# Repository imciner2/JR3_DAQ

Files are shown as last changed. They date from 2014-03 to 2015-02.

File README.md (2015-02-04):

JR3_DAQ
=======

Analog Data Acquisition unit for a JR3 Force/Moment sensor.

## Requirements:
* All connections must be idiot-proof
* Sealed box, only JR3 connector, computer connector, power connector
*	Raw voltage must be recorded

## Sensor:
It must interface with a JR3	67M25A3-I40-AH 200N. That sensor has the following features:
*	Requires a +-12V supply
*	Provides a +-10V output

## Digital Acquisition Hardware
It uses a NI USB-6221 DAQ in the OEM form-factor. That sensor has the following features:
*	16 analog inputs
*	250kS/s
*	Labview interface
*	http://sine.ni.com/nips/cds/view/p/lang/en/nid/209809
*	34-pin ribbon cable connector

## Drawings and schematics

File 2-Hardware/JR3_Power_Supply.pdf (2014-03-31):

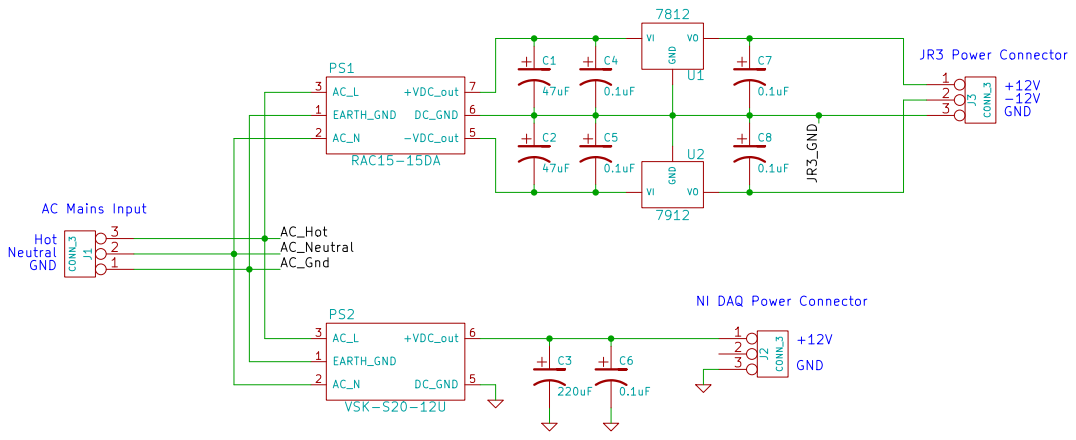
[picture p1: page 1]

AC Mains Input Hot Neutral GND

Drawn By: Ian McInerney
Iowa State University
File: JR3_Power_Supply.sch
Sheet: /
Title: JR3 DAQ Power Supply

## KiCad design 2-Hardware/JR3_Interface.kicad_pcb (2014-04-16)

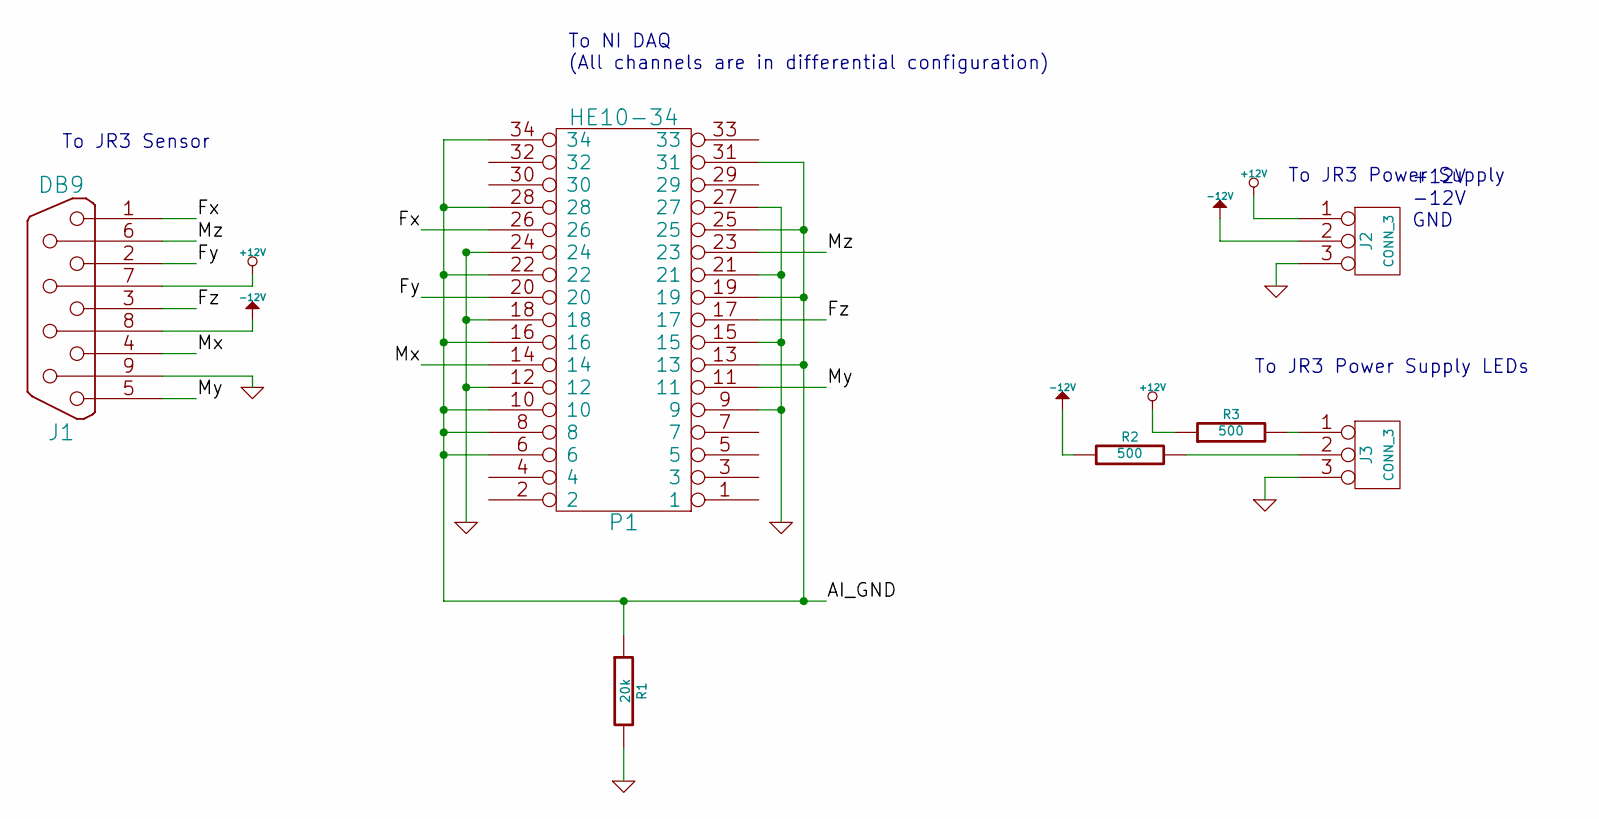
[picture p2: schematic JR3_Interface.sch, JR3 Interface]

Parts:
J1: DB9
J2, J3: CONN_3
P1: HE10-34
R1: 20k
R2, R3: 500

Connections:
+12V: J1.7, J2.1, R3.1
-12V: J1.8, J2.2 (PM), R2.1
/AI_GND: P1.6, P1.8, P1.10, P1.13, P1.16, P1.19, P1.22, P1.25, P1.28, P1.31, P1.34, R1.1
/Fx: J1.1, P1.26
/Fy: J1.2, P1.20
/Fz: J1.3, P1.17
/Mx: J1.4, P1.14
/My: J1.5, P1.11
/Mz: J1.6, P1.23
GND: J1.9, J2.3, J3.3, P1.9, P1.12, P1.15, P1.18, P1.21, P1.24, P1.27, R1.2
unnamed: J3.1, R3.2
unnamed: J3.2 (PM), R2.2

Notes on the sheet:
To JR3 Sensor
To NI DAQ (All channels are in differential configuration)
To JR3 Power Supply
To JR3 Power Supply LEDs
+12V -12V GND

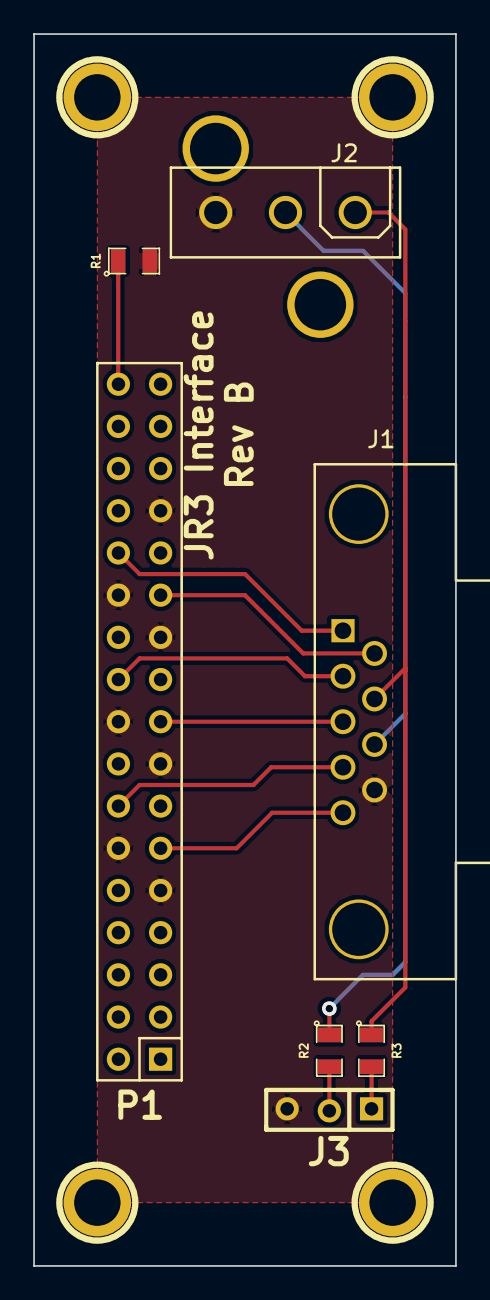
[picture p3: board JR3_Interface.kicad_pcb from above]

Board: 2 copper layers, 25.4 x 74.2 mm, 11 parts (0 on the bottom side), 12 nets.

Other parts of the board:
1PIN, 1PIN#2, 1PIN#3, 1PIN#4: P***; 1pin

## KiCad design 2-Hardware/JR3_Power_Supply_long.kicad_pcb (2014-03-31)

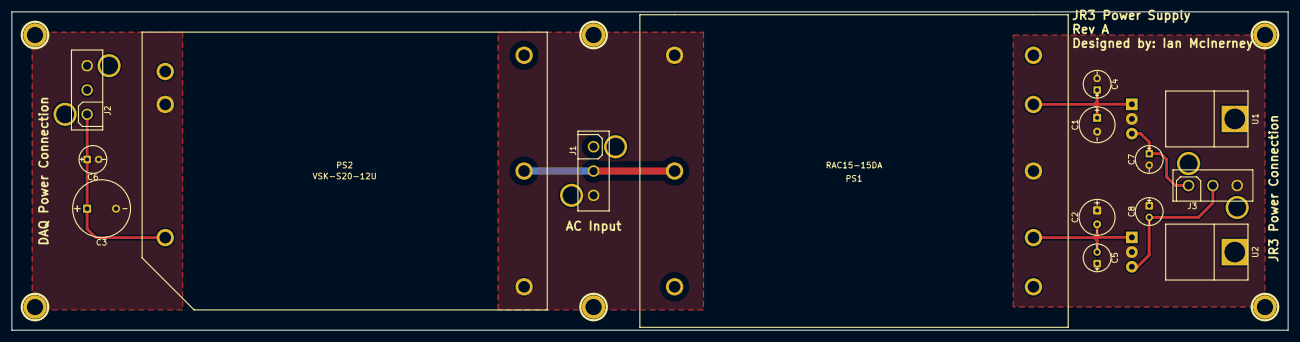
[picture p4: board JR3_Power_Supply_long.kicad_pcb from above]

Board: 2 copper layers, 220.5 x 55.0 mm, 21 parts (0 on the bottom side), 10 nets.

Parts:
1PIN, 1PIN#2, 1PIN#3, 1PIN#4, 1PIN#5, 1PIN#6: P***; 1pin
C1, C2: 47uF; C_2.5mm_6.3mm
C3: 220uF; C_5mm_10mm
C4, C5, C6, C7, C8: 0.1uF; C_2mm_5mm
J1, J2, J3: CONN_3; CONN_MINI-FIT-JR_3_TH
PS1: RAC15-15DA; PS_RACOM_RAC15
PS2: VSK-S20-12U; PS_CUI_VSK-S20
U1: 7812; TO220_HORIZ
U2: 7912; TO220_HORIZ

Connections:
/AC_Gnd: J1.1, PS1.1, PS2.1
/AC_Hot: J1.3, PS1.3, PS2.3
/AC_Neutral: J1.2, PS1.2, PS2.2
/JR3_GND: C1.2, C2.1, C4.2, C5.1, C7.2, C8.1, J3.3, PS1.6, U1.2, U2.2
GND: C3.2, C6.2, J2.3, PS2.5
unnamed: C8.2, J3.2, U2.3
unnamed: C7.1, J3.1, U1.3
unnamed: C1.1, C4.1, PS1.7, U1.1
unnamed: C2.2, C5.2, PS1.5, U2.1
unnamed: C3.1, C6.1, J2.1, PS2.6

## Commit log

2014-03-31 Initial commit of the hardware files from revision A.
    [JR3_Interface.kicad_pcb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]
2014-04-16 Fixes #3.
    Adds channels AI8-AI13 to the ground plane to create differential signaling channels.
    [JR3_Interface.sch]
2014-04-16 Fixes #5 and resolves #3. Also fixes the power connector footprint on this board.
    [JR3_Interface.kicad_pcb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]
2014-04-16 Manufacturing files for the Rev B board.
2014-04-16 Verified the gerber files.
    [JR3_Interface-B_Cu.gbl, JR3_Interface-B_Mask.gbs, JR3_Interface-Edge_Cuts.gbr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]
